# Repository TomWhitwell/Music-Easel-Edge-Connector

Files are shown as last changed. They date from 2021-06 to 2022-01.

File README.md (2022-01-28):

# Music Easel Edge Connector
 
 *** NB: THIS IS NOT FULLY TESTED, read below*** 
 
 This is an Eagle Library for the card edge for Buchla Music Easel expansion cards. This should work with BEMI Music Easels and clones, apart from the 208r rev1  which has different pinout. NB: I take no responsibility at all for anything designed using this part.
 
 This is just the edge connector library, and two boards showing the part in situ - neither of these board layouts will do anything. This is not a prototype board! 
 
 I've made a PCB with the minimal version, works well - put it on standard 1.6mm PCB with ENIG finish and no special edge treatment. I've checked my layout, but please carefully check for any errors as you're using it - it's not impossible that one of the traces could be incorrectly labelled. 
 

 

 There are two versions:
 
 The Full version is the whole bottom side of a standard program card. 
 
 

The Small / Minimal version is just the edge connector itself 



For both cards, take care to match the outline layer to the outline in the part - if you turn on tDocu layer, you'll see the measurements to make it easier to connect with the part 

The symbol has text explaining which pin is which: 



Things to watch out for: 
* The edge connector runs right up to the edge of the board, so you may get design rule errors, which you can probably ignore. 
* Eagle doesn't seem to understand that the outline layer in the part connects with the outline layer on the rest of the board, so it looks as if the outline layer is incomplete. However, this doesn't seem to be a real issue - the gerbers produced have a complete outline layer. 

Thank you to Marc Borri for his help with this, and for [Portabellabs](http://www.portabellabz.be/toolbox.html) for the pinout details, in the documentation for their excellent 208 Toolbox. 

This part was designed by Tom Whitwell in Herne Hill, London, in June 2021. You are free to use it however you want.

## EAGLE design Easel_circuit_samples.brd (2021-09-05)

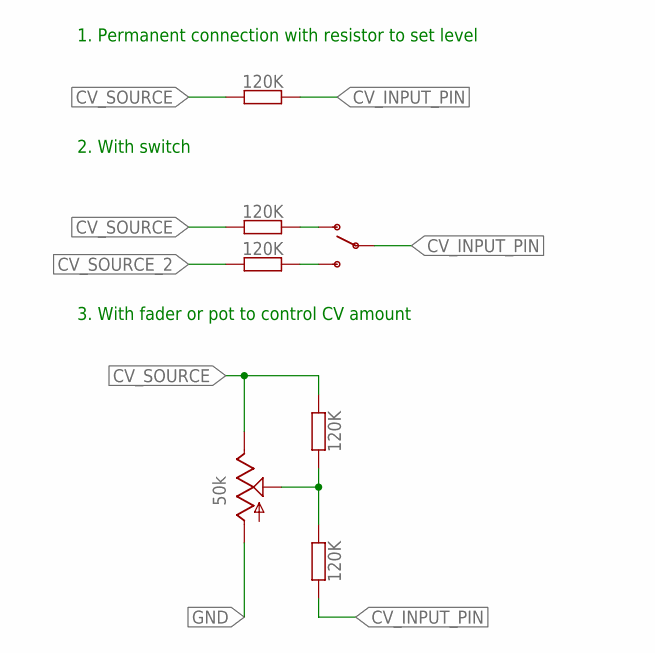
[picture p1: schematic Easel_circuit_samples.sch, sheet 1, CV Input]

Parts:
R1, R2, R3, R4, R5: 120K; C0603
S1: GRAYHILL_34E_SMD_TOGGLE; 34EWMSP12M6RT
VR1: 50k; 9MM_SNAP-IN_POT

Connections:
CV_INPUT_PIN: R2.1, R3.1, S1.2 (COMMON)
CV_SOURCE: R1.2, R3.2, R4.2, VR1.3 (E)
CV_SOURCE_2: R5.2
GND: VR1.1 (A); also elsewhere on the board
unnamed: R4.1, S1.1 (O)
unnamed: R1.1, R2.2, VR1.2 (S)
unnamed: R5.1, S1.3 (S)

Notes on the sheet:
3. With fader or pot to control CV amount
1. Permanent connection with resistor to set level
2. With switch

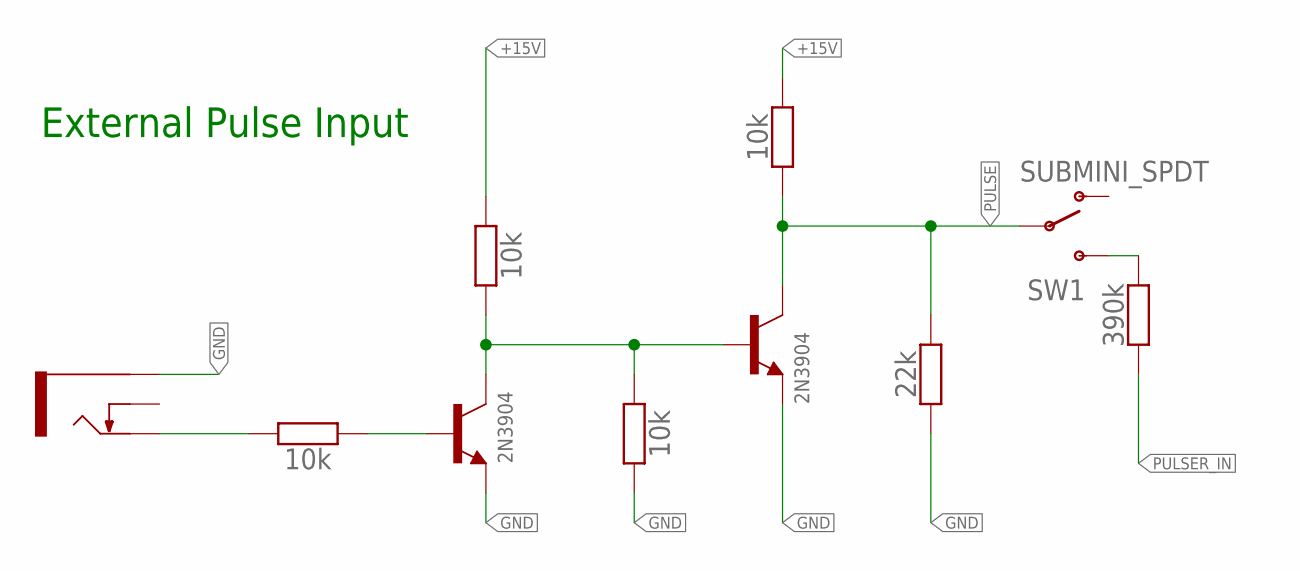
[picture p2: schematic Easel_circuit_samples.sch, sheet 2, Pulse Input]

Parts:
Q1: 2N3904; SC70-6
R6, R7, R8, R9: 10k; C0603
R10: 22k; C0603
R11: 390k; C0603
SW1: SUBMINI_SPDT; SUBMINI_TOGGLE
U1: THONKICONNNEW; WQP-PJ301M-12_JACK

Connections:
+15V: R7.2, R9.1
GND: Q1.1 (E), Q1.4 (E), R8.1, R10.2, U1.P$3_SLEEVE (SLEEVE); also elsewhere on the board
unnamed: R6.1, U1.P$1_TIP (TIP)
unnamed: Q1.5 (B), R6.2
unnamed: Q1.2 (B), Q1.3 (C), R7.1, R8.2
unnamed: R11.1, SW1.3 (S)
PULSE: Q1.6 (C), R9.2, R10.1, SW1.COM (COMMON)
PULSER_IN: R11.2

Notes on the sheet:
External Pulse Input

Board: 2 copper layers, 16 parts (0 on the bottom side), 12 nets, no tracks yet.

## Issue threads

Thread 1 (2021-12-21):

Pinout

TomWhitwell, 2021-12-21:
Front
1 : +15V
2 : 0V
3 : NC
4 : NC
5 : NC
6 : NC
7 : seq step 1 out
8 : seq step 3 out
9 : seq step 4 out
10 : seq step 5 out
11 : seq steps #
12 : seq pulse setting
13 : seq CV setting
14 : random pulse in
15 : seq CV out
16 : random 2 out
17 : EG pulse in
18 : pulser pulse out
19 : duration CV in
20 : pulser out
21 : decay CV in
22 : LPG1 level CV in
23 : MO ws CV in
24 : CO & MO key
25 : LPG2 level CV in
26 : preamp "to prog"
27 : LPG2 mode switch CV in
28 : inverter "from prog"

Rear
1 : -15V
2 : NC
3 : NC (+5V on BEMI 208)
4 : NC
5 : NC
6 : NC
7 : seq step 2 out
8 : random 1 out
9 : pulser period CV in
10 : MO index CV in
11 : MO freq CV in
12 : sequencer pulse in
13 : CO pitch CV in
14 : keyboard pulse out
15 : keyboard key CV out
16 : pulser pulse in
17 : timbre CV in
18 : attack CV in
19 : keyboard pressure CV out
20 : EG CV out
21 : sequencer pulse out
22 : MO modulation switch CV in
23 : inverter "to prog"
24 : CO waveshape pot CV in
25 : CO waveshape switch CV in
26 : LPG1 mode switch CV in
27 : offset (+13.5V)
28 : signal routing switch CV

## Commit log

2021-06-27 Minor updates
    [Easel_Edge_Connnector_Full.brd, Easel_Edge_Connnector_Full.sch, Easel_Edge_Connnector_Minimal.brd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]
2021-07-06 Straightened bottom edge on both footprints
2021-07-06 Remove solder paste from edge connector pads
2021-09-05 remove cruft
    [Easel_circuit_samples.brd, Easel_circuit_samples.sch]
2022-02-08 Add right aligned full card edge connector
2022-02-08 fixed right aligned edge connector

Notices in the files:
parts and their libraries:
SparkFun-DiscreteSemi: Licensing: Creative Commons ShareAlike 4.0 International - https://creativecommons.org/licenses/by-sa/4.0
